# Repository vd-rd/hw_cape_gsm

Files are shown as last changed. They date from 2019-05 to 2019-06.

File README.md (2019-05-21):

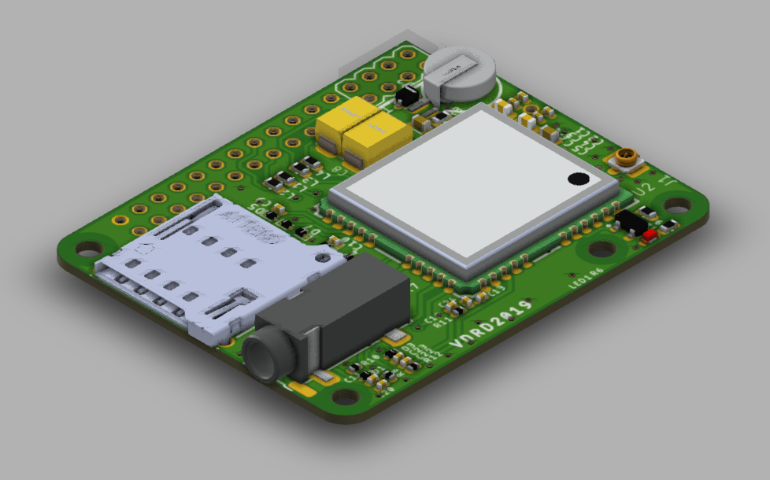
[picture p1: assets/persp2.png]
board image


## Description
Open hardware module for providing communications support via GPRS to embedded projects. The module can use any 2G network operating in the 850/900MHz or 1800/1900MHz spectrum. The modem features an audio link for voice calls and a TCP/IP stack for data transfer.

## Documentation

 Documentation for the module is available in the [docs folder](docs).
 
 Various resources used to design the module are available in the [resources folder](resources).

### Features
 * MicroSIM connector
 * 3.5mm jack with microphone
 * status LED indicator
 * two serial ports ( ATcommands on main serial port and support for daisy chaining a second UART device)
 * standard u.FL connector for antenna
 * standard ApolloIoT expansion header

### Resources
You can find all necesary information to build or evaluate the module here:
   - [View 3D board render](https://a360.co/2FHexOh)
   - [Fabrication files](https://github.com/vd-rd/hw_cape_gsm/releases)

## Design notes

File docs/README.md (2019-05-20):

## Table of contents

1. [Bill of materials](BOM.md)
2. [Assembly variants](ASSEMBLY.md)
3. [Mechanical overview](MECHANICAL.md)
4. [Electrical connections](ELECTRICAL.md)
5. [Getting started](INIT.md)

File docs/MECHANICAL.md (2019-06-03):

## Board outline
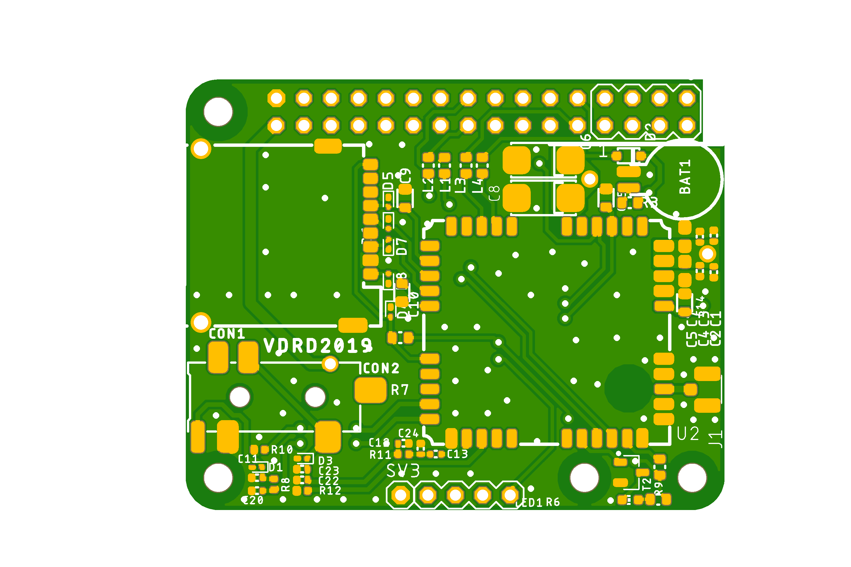
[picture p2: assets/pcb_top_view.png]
board top

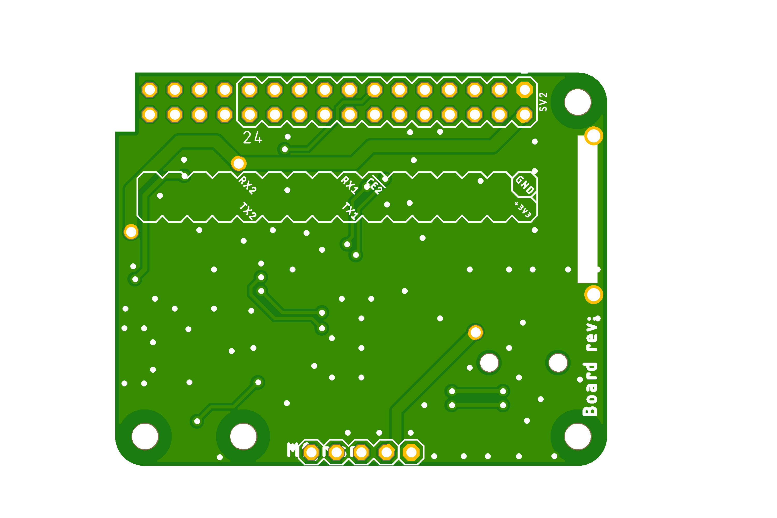
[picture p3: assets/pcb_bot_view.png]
board bot


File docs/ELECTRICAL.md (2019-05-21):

## Headers

The board features two headers for interfacing with the module. One is the standard Apollo.IoT expansion header with the following signals routed to the module:

| Pin | Signal | Description | Observations |
| --- | --- | --- | --- |
| 1 | GND | Board ground reference |
| 2 | VSYS | +3V3 regulated supply | Used as power supply for the node |
| 13 | CAPE_EN1 | PWR signal | Used to power cycle the module |
| 15 | UART2_TXD | |
| 16 | UART2_RXD | |
| 23 | UART1_RXD | |
| 24 | UART1_TXD | |

Breakout header:

| Pin | Signal | Description | Observations |
| --- | --- | --- | --- |
| 1 | GND | Board ground reference |
| 2 | VSYS | +3V3 regulated supply | Used as power supply for the node |
| 3 | UART1_RXD | |
| 4 | UART1_TXD | |
| 5 | CAPE_EN1 | PWR signal | Used to power cycle the module |

## Observations
 * +3v3 signal should be able to sustain 2A peak signals with a medium consumption of 100mA.
 * PWR pin has an internal pull-up. Pull low for at least 100ms to wake the module or power down.
 * UART1 is the main communication interface. It supports AT commands for various functions.
 * UART2 is used to communicate with a GPS module. The information is accesible via the first UART using AT commands.

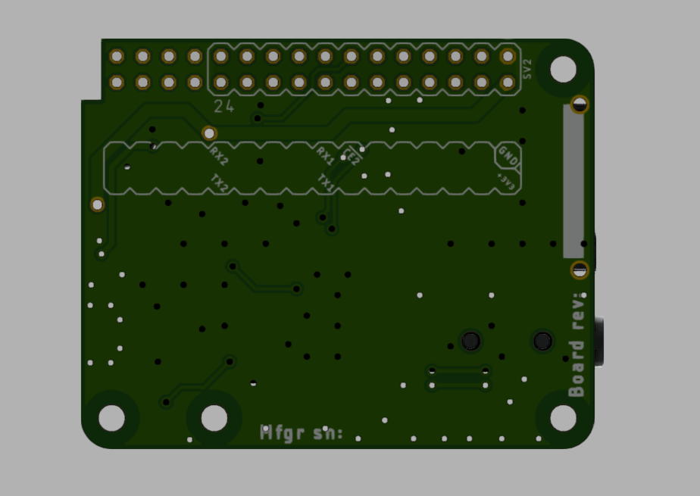
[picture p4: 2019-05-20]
assets/bottom.png

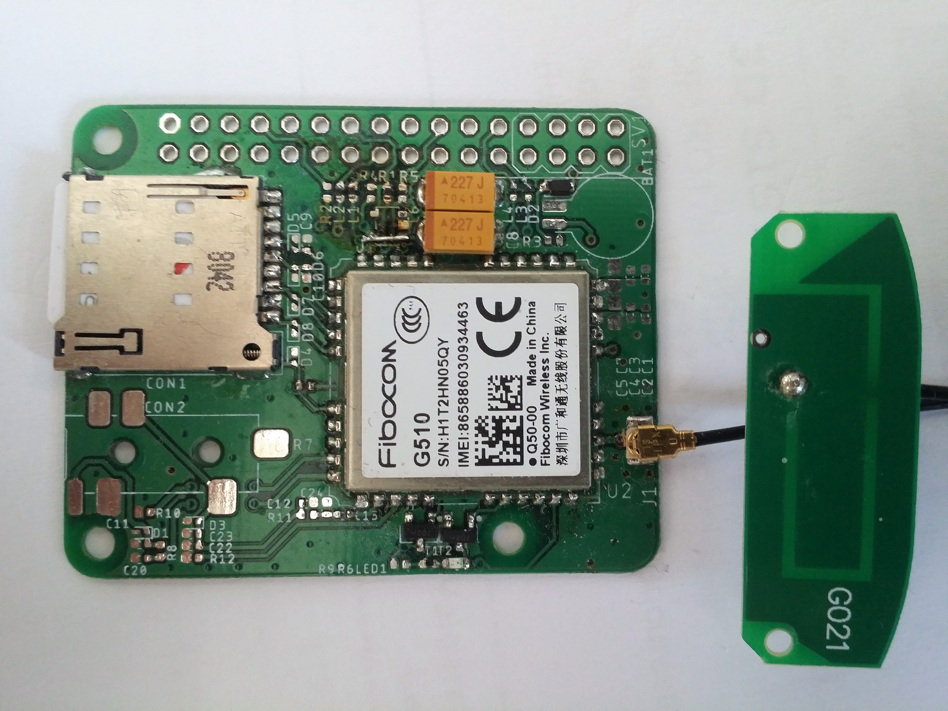
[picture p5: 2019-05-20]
assets/board.jpg

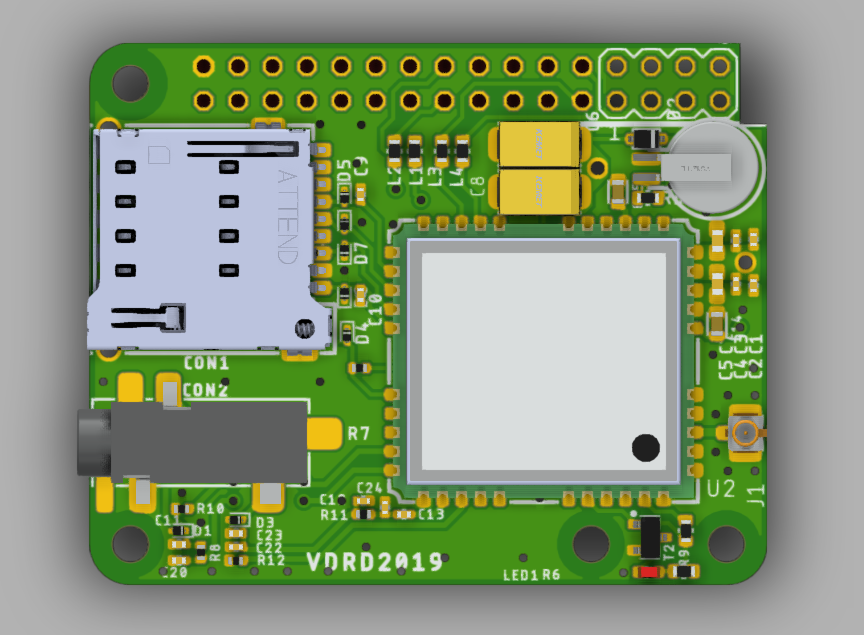
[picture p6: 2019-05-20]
assets/top.png

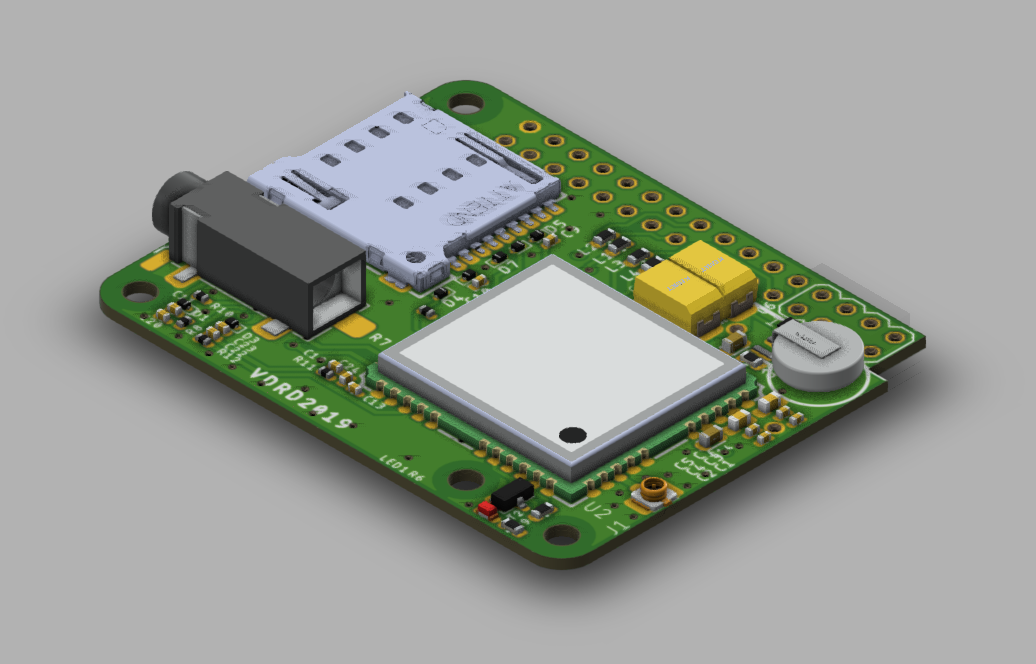
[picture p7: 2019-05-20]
assets/persp.png

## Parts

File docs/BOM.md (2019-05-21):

## Revision 1.0 BOM

[Complete BOM and example parts](https://docs.google.com/spreadsheets/d/138vCS7z_F9O98r_FUHqWK47GeZZgn0T5hS3GLevilZI/edit?usp=sharing)

| Qty | Parts | Package | Value | Description | Part id |
| --- | --- | --- |--- | --- | --- |
| 1 | CON1 |	| |	Connector: for cards; Micro SIM; push-push; SMT; PIN: 8	| 115Q-BCA0 |
| 2	| C14, C15 |	0603 | 100nF |	Capacitor: ceramic; MLCC; 100nF; 16V; X7R; ±10%; SMD; 0603 |	CL10B104KO8NNNC |
| 7	| D1, D3, D4, D5, D6, D7, D8 |	SOD923 | | Diode: transil; 300mW; 7.8V; 15A; bidirectional; SOD923 |	ESD9B5.0ST5G |
| 4	| L1, L2, L3, L4 |	0603 | |		Ferrite: bead; Imp.@ 100MHz: 120Ω; Mounting: SMD; 0.2A; Case: 0603 |	BLM18AG121SN1D |
|2	| R7, R9 |	0603 |	100k |	Resistor: thick film; SMD; 0603; 100kΩ; 0.1W; ±5%; -55÷155°C |	SMD0603-100K |
| 1	| C7 |	 0603 |	100nF |	Capacitor: ceramic; MLCC; 100nF; 16V; X7R; ±10%; SMD; 0603 |	CL10B104KO8NNNC |
| 2	| C5, C10 |	 0603 |	10nF |	Capacitor: ceramic; MLCC; 10nF; 50V; X7R; ±10%; SMD; 0603 |	VJ0603Y103KXAPW1BC |
| 1	| C2 |	0402 |	10pF |	Capacitor: ceramic; MLCC; 10pF; 50V; C0G; ±0.5pF; SMD; 0402 |	0402N100D500CT |
| 2	| C6, C8 |	SMC_C |	220uF |	Capacitor: tantalum; 220uF; 4VDC; SMD; Case: C; 2312; ±10%; -55÷125°C	| TAJC227K004R |
| 1	| C3 |	0402 |	33pF |	Capacitor: ceramic; 33pF; 50V; C0G; ±5%; SMD; 0402; Series: GRM	| GRM1555C1H330JA01D |
| 1	| C4 |	0402 |	39pF |	Capacitor: ceramic; 39pF; 50V; C0G; ±5%; SMD; 0402; Series: GRM	| GRM1555C1H390JA01D |
| 1	| C1 | 0402 |	8.2pF	| Capacitor: ceramic; 8.2pF; 50V; C0G; ±0.25pF; SMD; 0402; Series: GRM |	GRM1555C1H8R2CA01D |
| 1	| U2 | | | Module: GSM; GPRS; 2G; D: 85.6kbps; Audio x2,GPIO,UART x2; -40÷85°C |	G510-Q50-00 |
| 1	| J1 | | | Connector: U.FL (IPX/AMC); socket; 50Ω; SMT; male; 1.25mm |	MX-73412-0114 |
| 1 |	LED1 |	CHIP-LED0603 | | LED	
| 1	| D2 |	SOD323 | | 1N4148			
| 1 |	BAT1 |	621 | |	DCK-3R3E404T-E
| 1	| T2 |	SOT23 | |	2N7002		
| 2	| R3, R6 |	0603|	180 | 
| 1 |	CON2 |				
| 1 |	R8 |	R0402 | |	RESISTOR, European symbol	 |
| 2 |	R10, R12 | 	R0402 | 0 |	RESISTOR, European symbol	|
| 1 |	R11 |	R0402 |	10 |	RESISTOR, European symbol	|
| 2	| C23	| C0402K |	10pF |		
| 1	| C13 |	C0402K |	1uF |		
| 7	| C3, C9, C11, C12, C20, C22, C24 |	C0402K |	33pF |

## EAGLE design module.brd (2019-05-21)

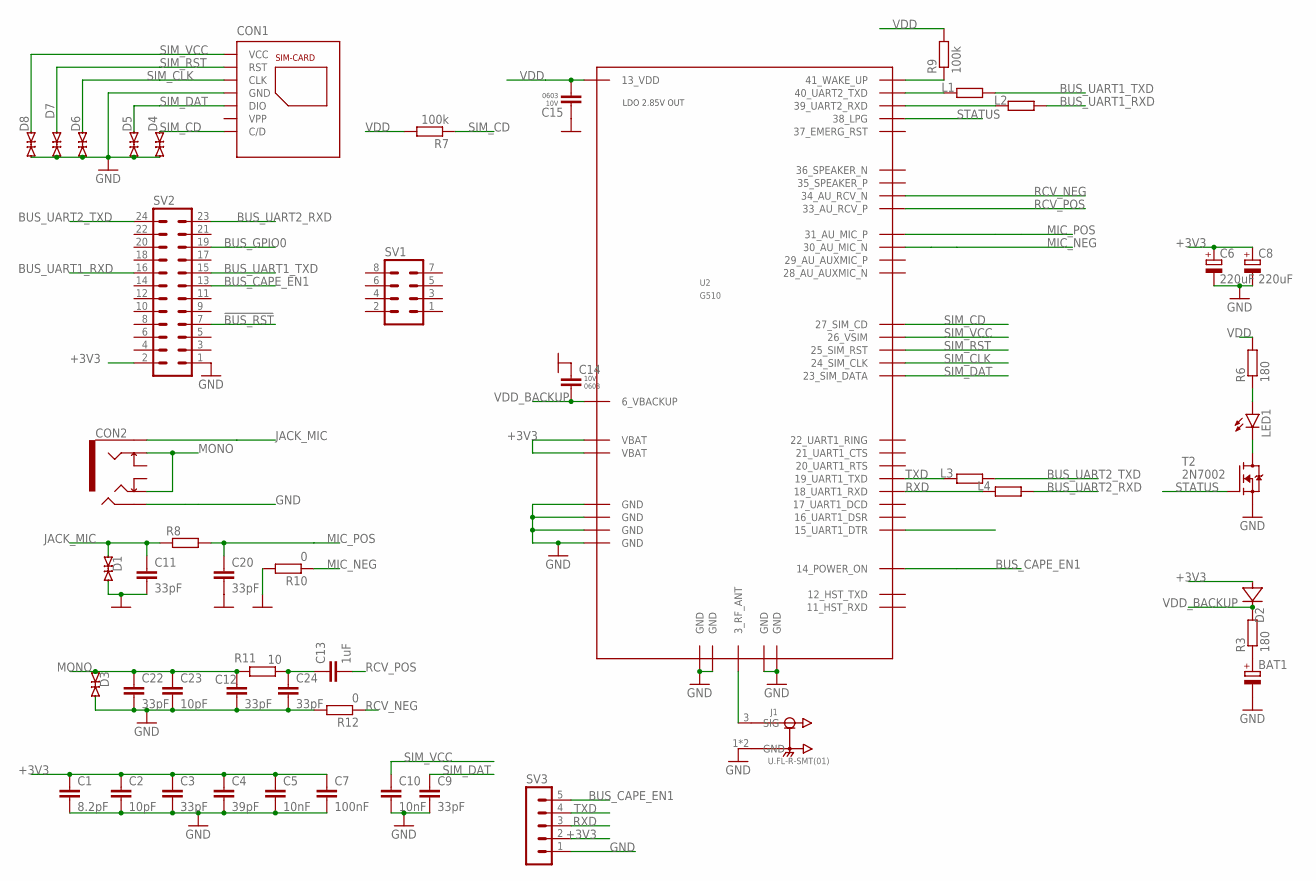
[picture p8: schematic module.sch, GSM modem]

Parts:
BAT1: DCK-3R3E224U-E; 621
C1: 8.2pF; C0402K
C2, C23: 10pF; C0402K
C3, C11, C12, C20, C22, C24: 33pF; C0402K
C4: 39pF; C0402K
C5, C10: 10nF; C0603
C6, C8: 220uF; SMC_C
C7: 100nF; C0603
C9: 33pF; C0603
C13: 1uF; C0402K
C14, C15: CAP-0603; C0603
CON1: 115Q-BCA0; 115Q
CON2: 1503-21; 150321
D1, D3, D4, D5, D6, D7, D8: ESD9B5.0ST5G; SOD1006X40
D2: 1N4148WS; SOD323
J1: U.FL-R-SMT(01); HRS_U.FL-R-SMT(01)
L1, L2, L3, L4: RES-0603; R0603
LED1: LEDCHIP-LED0603; CHIP-LED0603
R3, R6: 180; R0603
R7, R9: 100k; R0603
R8: R-EU_R0402; R0402
R10, R12: 0; R0402
R11: 10; R0402
SV1: MA04-2
SV2: MA12-2
SV3: MA05-1
T2: 2N7002; SOT95P240X110-3
U2: G510

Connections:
!BUS_RST: SV2.7
+3V3: C1.1, C2.1, C3.1, C4.1, C5.1, C6.+, C7.1, C8.+, D2.A, SV2.2, SV3.2, U2.9_VBAT (VBAT), U2.10_VBAT (VBAT)
BUS_CAPE_EN1: SV2.13, SV3.5, U2.14_POWER_ON
BUS_GPIO0: SV2.19
BUS_UART1_RXD: L2.2, SV2.16
BUS_UART1_TXD: L1.2, SV2.15
BUS_UART2_RXD: L4.2, SV2.23
BUS_UART2_TXD: L3.2, SV2.24
GND: BAT1.-, C1.2, C2.2, C3.2, C4.2, C5.2, C6.-, C7.2, C8.-, C9.2, C10.2, C11.2, C12.2, C14.1, C15.1, C20.2, C22.2, C23.2, C24.2, CON1.GND1 (GND), CON1.GND2 (GND), CON1.GND3 (GND), CON1.GND4 (GND), CON1.P5 (GND), CON2.2, D1.2 (C), D3.2 (C), D4.1 (A), D5.1 (A), D6.1 (A), D7.1 (A), D8.1 (A), J1.1 (GND), J1.2 (GND), R10.2, R12.2, SV2.1, SV3.1, T2.2 (S), U2.1_GND (GND), U2.2_GND (GND), U2.4_GND (GND), U2.5_GND (GND), U2.7_GND (GND), U2.8_GND (GND), U2.32_GND (GND), U2.42_GND (GND)
JACK_MIC: C11.1, CON2.1, D1.1 (A), R8.1
MIC_NEG: R10.1, U2.30_AU_MIC_N
MIC_POS: C20.1, R8.2, U2.31_AU_MIC_P
MONO: C12.1, C22.1, C23.1, CON2.3, CON2.5, D3.1 (A), R11.2
unnamed: BAT1.+, R3.1
unnamed: C13.1, C24.1, R11.1
unnamed: J1.3 (SIG), U2.3_RF_ANT
unnamed: LED1.C, T2.3 (D)
unnamed: R9.1, U2.41_WAKE_UP
unnamed: LED1.A, R6.1
RCV_NEG: R12.1, U2.34_AU_RCV_N
RCV_POS: C13.2, U2.33_AU_RCV_P
RXD: L4.1, SV3.3, U2.18_UART1_RXD
SIM_CD: CON1.CD (C/D), D4.2 (C), R7.1, U2.27_SIM_CD
SIM_CLK: CON1.P3 (CLK), D6.2 (C), U2.24_SIM_CLK
SIM_DAT: C9.1, CON1.P7 (DIO), D5.2 (C), U2.23_SIM_DATA
SIM_RST: CON1.P2 (RST), D7.2 (C), U2.25_SIM_RST
SIM_VCC: C10.1, CON1.P1 (VCC), D8.2 (C), U2.26_VSIM
STATUS: T2.1 (G), U2.38_LPG
TXD: L3.1, SV3.4, U2.19_UART1_TXD
UART_RXD: L2.1, U2.39_UART2_RXD
UART_TXD: L1.1, U2.40_UART2_TXD
VDD: C15.2, R6.2, R7.2, R9.2, U2.13_VDD
VDD_BACKUP: C14.2, D2.K (C), R3.2, U2.6_VBACKUP

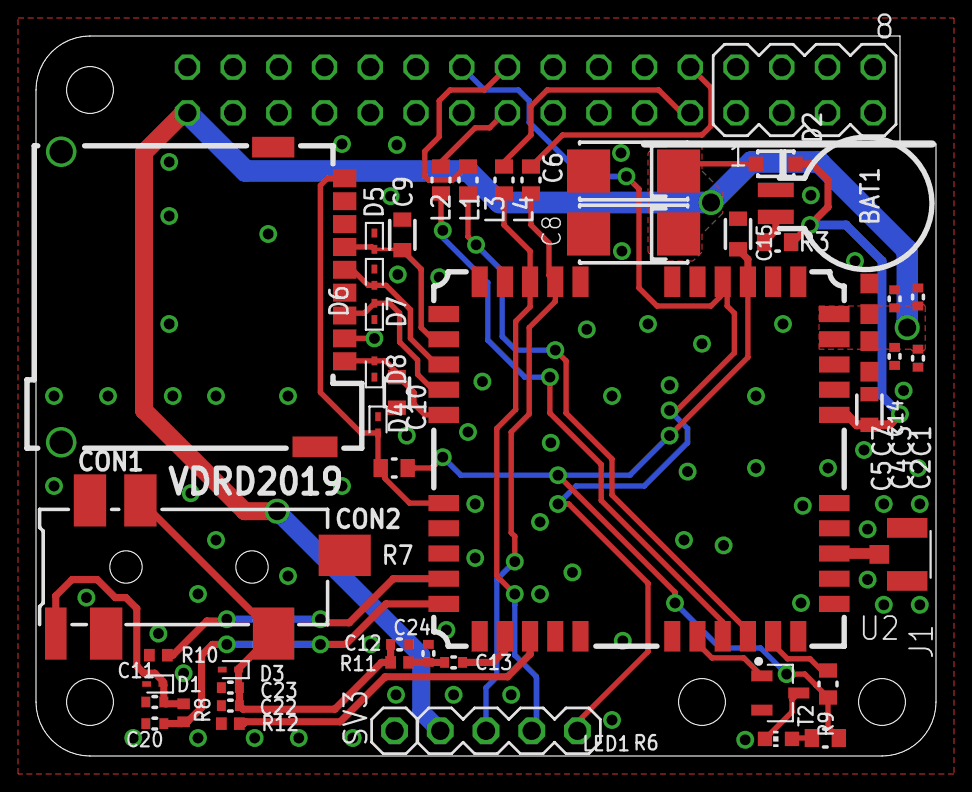
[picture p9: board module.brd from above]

Board: 2 copper layers, 50.0 x 40.0 mm, 49 parts (1 on the bottom side), 31 nets.

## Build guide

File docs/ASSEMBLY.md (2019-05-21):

### Description

The board has basic functionality implemented with the use of this components. The passive components are given as reference and can be swapped with different parts as long as the value is the same or in close proximity.

| Qty | Parts | Package | Value | Description | Part id |
| --- | --- | --- |--- | --- | --- |
| 1 | CON1 |	| |	Connector: for cards; Micro SIM; push-push; SMT; PIN: 8	| 115Q-BCA0 |
| 2	| C14, C15 |	0603 | 100nF |	Capacitor: ceramic; MLCC; 100nF; 16V; X7R; ±10%; SMD; 0603 |	CL10B104KO8NNNC |
| 7	| D1, D3, D4, D5, D6, D7, D8 |	SOD923 | | Diode: transil; 300mW; 7.8V; 15A; bidirectional; SOD923 |	ESD9B5.0ST5G |
| 4	| L1, L2, L3, L4 |	0603 | |		Ferrite: bead; Imp.@ 100MHz: 120Ω; Mounting: SMD; 0.2A; Case: 0603 |	BLM18AG121SN1D |
|2	| R7, R9 |	0603 |	100k |	Resistor: thick film; SMD; 0603; 100kΩ; 0.1W; ±5%; -55÷155°C |	SMD0603-100K |
| 1	| C7 |	 0603 |	100nF |	Capacitor: ceramic; MLCC; 100nF; 16V; X7R; ±10%; SMD; 0603 |	CL10B104KO8NNNC |
| 2	| C5, C10 |	 0603 |	10nF |	Capacitor: ceramic; MLCC; 10nF; 50V; X7R; ±10%; SMD; 0603 |	VJ0603Y103KXAPW1BC |
| 1	| C2 |	0402 |	10pF |	Capacitor: ceramic; MLCC; 10pF; 50V; C0G; ±0.5pF; SMD; 0402 |	0402N100D500CT |
| 2	| C6, C8 |	SMC_C |	220uF |	Capacitor: tantalum; 220uF; 4VDC; SMD; Case: C; 2312; ±10%; -55÷125°C	| TAJC227K004R |
| 1	| C3 |	0402 |	33pF |	Capacitor: ceramic; 33pF; 50V; C0G; ±5%; SMD; 0402; Series: GRM	| GRM1555C1H330JA01D |
| 1	| C4 |	0402 |	39pF |	Capacitor: ceramic; 39pF; 50V; C0G; ±5%; SMD; 0402; Series: GRM	| GRM1555C1H390JA01D |
| 1	| C1 | 0402 |	8.2pF	| Capacitor: ceramic; 8.2pF; 50V; C0G; ±0.25pF; SMD; 0402; Series: GRM |	GRM1555C1H8R2CA01D |
| 1	| U2 | | | Module: GSM; GPRS; 2G; D: 85.6kbps; Audio x2,GPIO,UART x2; -40÷85°C |	G510-Q50-00 |
| 1	| J1 | | | Connector: U.FL (IPX/AMC); socket; 50Ω; SMT; male; 1.25mm |	MX-73412-0114 |

Additional functionalities such as battery backup and audio link for voice calls is grouped and can be added by populating the necessary components.

Led indicator and battery backup:

| Qty | Parts | Package | Value | Description | Part id |
| --- | --- | --- |--- | --- | --- |
| 1 |	LED1 |	CHIP-LED0603 | | LED	
| 1	| D2 |	SOD323 | | 1N4148			
| 1 |	BAT1 |	621 | |	DCK-3R3E404T-E
| 1	| T2 |	SOT23 | |	2N7002		
| 2	| R3, R6 |	0603|	180 | 		

Audio jack for calls (w/ microphone):

| Qty | Parts | Package | Value | Description | Part id |
| --- | --- | --- |--- | --- | --- |
| 1 |	CON2 |				
| 1 |	R8 |	R0402 | |	RESISTOR, European symbol	 |
| 2 |	R10, R12 | 	R0402 | 0 |	RESISTOR, European symbol	|
| 1 |	R11 |	R0402 |	10 |	RESISTOR, European symbol	|
| 2	| C23	| C0402K |	10pF |		
| 1	| C13 |	C0402K |	1uF |		
| 7	| C3, C9, C11, C12, C20, C22, C24 |	C0402K |	33pF |

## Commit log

2018-12-13 board bringup and floorplan
    [v0.1.0.brd, v0.1.0.sch]
2018-12-14 added support components
    [v0.1.0.brd, v0.1.0.sch]
2018-12-14 added audio filtering
    [v0.1.0.brd, v0.1.0.sch]
2018-12-21 corrected sim connector
    [v0.1.0.brd, v0.1.0.sch]
2018-12-21 removed extra caps
    [v0.1.0.brd, v0.1.0.sch]
2018-12-21 routed most nets
    [v0.1.0.brd, v0.1.0.sch]
2018-12-21 routed new nets
    [v0.1.0.brd, v0.1.0.sch]
2018-12-21 floorplan optimisations
    [v0.1.0.brd, v0.1.0.sch]
2018-12-21 added vias for ground emi
    [v0.1.0.brd]
2018-12-21 naming fixes
    [v0.1.0.brd]
2018-12-21 minor fixes'
    [v0.1.0.brd]
2019-01-07 bench tested
    [v0.2.0.brd, v0.2.0.sch, v0.3.0.brd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]
2019-01-08 improved ground emi
    [v0.4.0.brd, v0.4.0.sch]
2019-01-20 updated footprints
    [v0.4.0.brd, v0.4.0.sch]
2019-01-20 improved audio interface
    [v0.5.0.brd, v0.5.0.sch]
2019-01-20 cosmetic fixes
    [v0.5.0.brd, v0.5.0.sch]
2019-01-22 added jack switch docs
2019-01-23 added output files
    [v0.5.0.brd, v0.5.0.sch]
2019-03-12 space optimisation
    [v0.5.0.csv, v0.9.0.brd, v0.9.0.sch]
2019-05-02 project: structure update
    [module.brd, module.sch, v0.1.0.brd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]
2019-05-02 project: old files cleanup
    [v0.5.0.csv]
2019-05-20 board: add pinout and markings
    [module.brd, module.sch]
2019-05-20 project: added pictures
    [module.brd]
2019-05-20 Board: add breakout header
    [module.brd, module.sch]
2019-05-20 board: added mechanical data
    [module.brd, module.sch]
2019-05-21 project: added board overview
2019-05-21 board: added breakout header
    [module.brd, module.sch]
2019-05-21 project: prepared v1.1.0 rev
    [module.brd]
